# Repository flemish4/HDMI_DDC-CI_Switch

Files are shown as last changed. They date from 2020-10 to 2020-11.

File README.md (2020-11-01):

# HDMI_DDC/CI_KVM

## Introduction

This project aims to replicate the functionality of a KVM switch using the DDC/CI capability built into most monitors. 
This avoids the need for any complex switching of high frequency HDMI/DP signals so is cheap to implement and does not constrain the resolution or frequency of the monitor.
The additional important benefit is that most KVM switches do not handle EDID/hot plug detection correctly. This means that when the switch connects PC2 to the monitor(s), PC1 forgets that the monitors exist, and rearranges all the windows - annoying! This project avoids this problem because the monitors are all directly connected to each PC, so the monitor always provides EDID data and HPD signal.
It also serves as a demonstrator for communicating with monitors over DDC/CI.

## Status

<b>This project is currently dead because if a monitor is set to an input which is not active, most monitors go to sleep. From this sleep state, even when the input is changed using DDC/CI monitors often do not wake up.
I am not sure how monitors detect whether an input is active and if this could be fooled. I suspect it detects some of the high frequency HDMI signals. If these were replicated there wouldn't be much benefit over a normal KVM.
<h3>If anyone has a solution to this problem please get in touch and we can have cheap multi monitor KVMs!</h3>
If your monitors correctly switch away from idle inputs to active inputs, this project may work well.</b>

Normal KVMs should implement a DDC/CI/HPD scheme, where each PC always believes it is connected to its monitors at all times, this project shows that it isn't very difficult. Simply read EDID from the monitor, then repeat this every time the PC asks for the information. If anyone is aware of a dual monitor KVM that handles this correctly please let me know! :)

## Setup

The project was tested on an arduino uno, with vscode and platformio as the ide. The only external components required are: 4 resistors (i2c pullups), 2 resistors (HDMI 5v current limiting - should really be an IC), 5 push buttons and two female HDMI ports with only have 5v, GND, I2CDAT, I2CCLK signals connected. These are connected to a spare input on each monitor (so each monitor requires 3+ inputs).
See end of readme for schematic and diagram.
## Usage - Overview

The project implements 5 buttons, 1 'setup' button and 4 'mode' buttons.
See end of readme for flow diagram.
At idle, the 'mode' buttons can either select a preset mode, or can relate to each monitor and each button will cycle through each input for that monitor. You can switch between these two idle states by pressing the 'setup' button.
To set presets, simply hold setup, then within 1 second press the button you wish to set a preset on, wait 3 seconds. This will set the preset to the current state of the monitors.
There is also a settings menu which can be accessed by pressing 'setup' for 4 seconds.
You can configure :
    default (turn on) idle state (preset selection or input switching)
    default (turn on) monitor state (leave monitors as they are, change them to the inputs selected when the switch turned off, or any of the presets)
    input selection options (0: Automatic detection (order will likely be wrong), 1: Match mode order (likely in order but may miss extras), 2: Match mode order + autodetected (likely in order but may have extras), 3: Automatic detection (ordering will likely be wrong) - test ALL possible values) 
At any time in the menu, press 'setup' to exit the menu.

## Initial Setup and Normal Use

 1. Turn on for the first time with monitors connected and PCs turned on
 2. Press and hold 'setup' for 5 seconds, until the LED flashes in short single beat pulses - this is the settings menu
 3. Press Button 2 (the third mode button, the 4th button if you include the setup button) - this selects input setup
 4. Press Button 0 for automatic input detection - this will take a few seconds to cycle through every input on every monitor
3. Press 'setup' to return to idle
4. Press 'setup' again to switch to input selection state
5. Press Buttons 0 and 1, the monitors should cycle through their inputs
6. Press 'setup' then one of the mode buttons and hold for 5 seconds - this sets the current input configuration as that mode - repeat until all desired modes are set
1. Press 'setup' to enter mode selection state
1. Press any of the set mode buttons - the monitors should switch to that configuration!

## Full settings menu description
Pressing 'setup' at any time will return you to idle, not in settings menu.
Completing any operation in settings menu will return you to Main settings menu.
|Level 0|Level 1|Level 2|Level 3|
|--|--|--|--|
|Main|
||0. Change setup button behaviour||
|||0. Mode select|
||| 1. Input select|
||1. Change turn on behaviour||
|||0. Do not change|
|||1. As turn off state|
|||2. Select mode|
||||0,1,2,3. Respective mode is set|
||2. Configure monitor input switching||
|||0. Automatic detection|
|||1. Extract in order from preset modes|
|||2. Extract from modes then add any extras found during automatic detection|
||3. (Not fully implemented) Change serial debug levels||
|||0. No debug|
|||1. Errors only|
|||2. Warnings and errors|
|||3. All debug|

## Future if sleep issue is overcome
If the sleep problem could be fixed, the next phase was to implement HDMI passthrough. In this case, HDMI signals would be passed through so that no extra input is required. The only additional complexity is a gate between the HDMI input and output on the i2c lines, to enable the HDMI_DDC/CI_KVM to change the input (removing the PC master). This should be relatively simple, if PCs are able to notice this disconnect, it may be possible to hold the i2c clk line low until the input switching is complete, which should make the PC wait.

## References
|Name|Description/use|Link|
|--|--|--|
|DDC/CI VESA specification|Contains semi helpful descriptions of how DDC/CI i2c communication works - actual VCP codes are in appendix|https://milek7.pl/ddcbacklight/ddcci.pdf|
|MCCS (VCP) VESA specification|Contains VCP descriptions, layout of data|https://milek7.pl/ddcbacklight/mccs.pdf|
|ControlMyMonitor|Useful utility for using DDC/CI from windows - used to trigger communication which captured for reference|https://www.nirsoft.net/utils/control_my_monitor.html|
|ddcutil|Similar to ControlMyMonitor but linux only looks well maintained - documentation contains useful snippets|https://www.ddcutil.com/|

## Diagrams

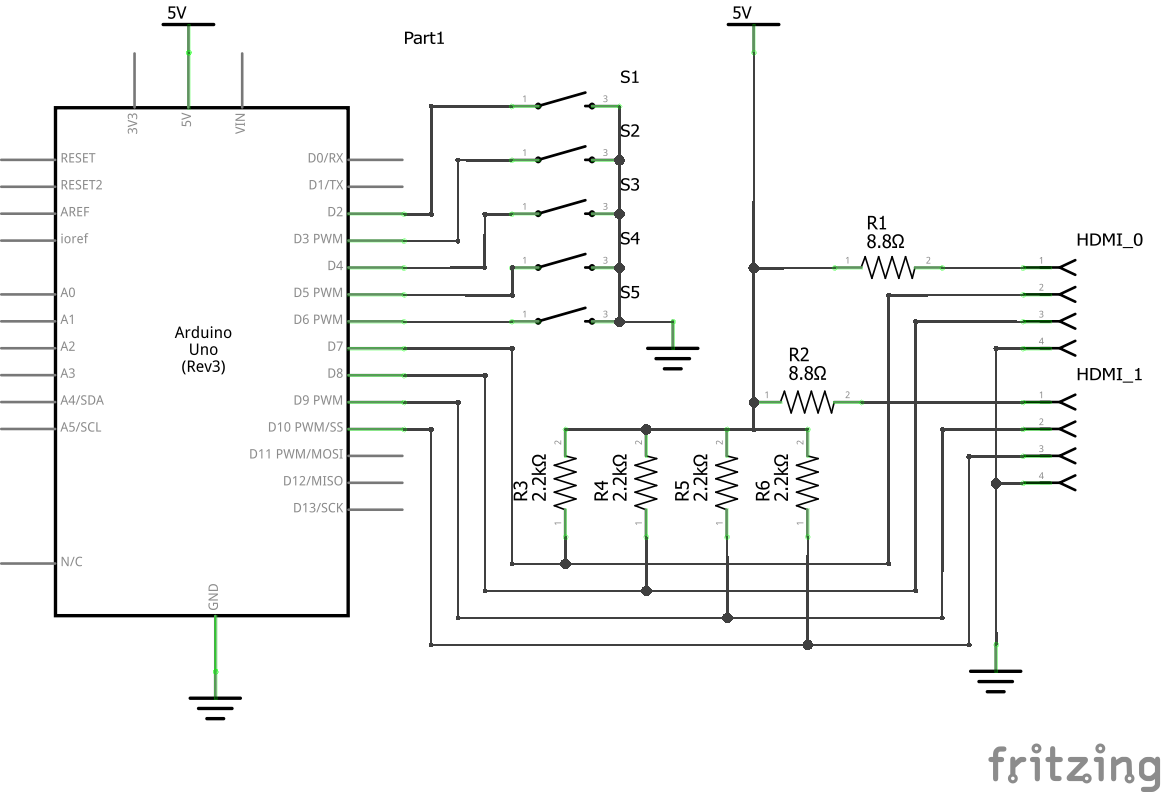
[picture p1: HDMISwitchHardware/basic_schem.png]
Schematic

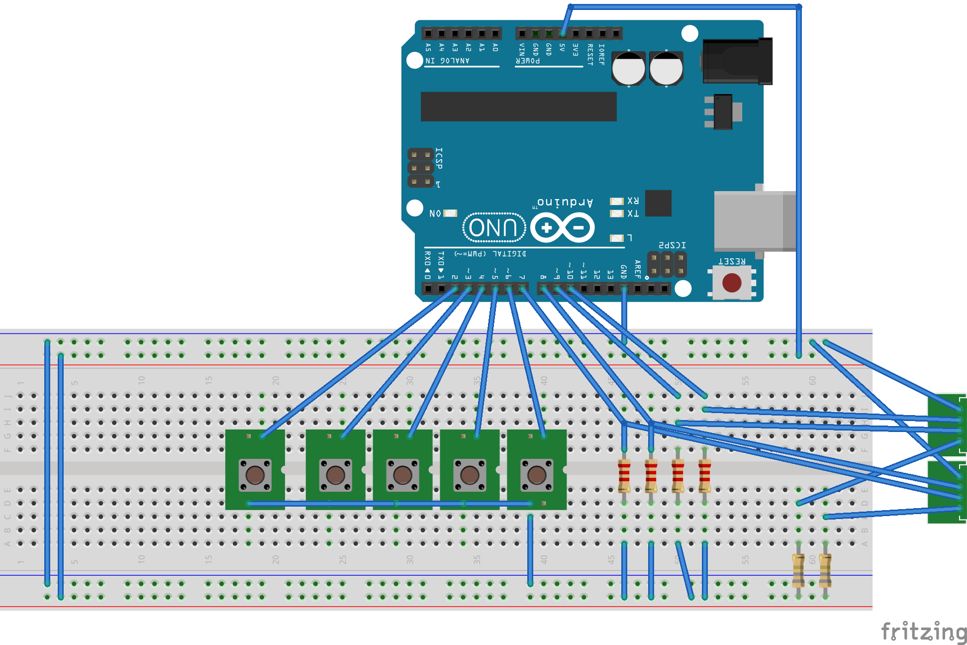
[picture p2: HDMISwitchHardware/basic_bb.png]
Fritzing

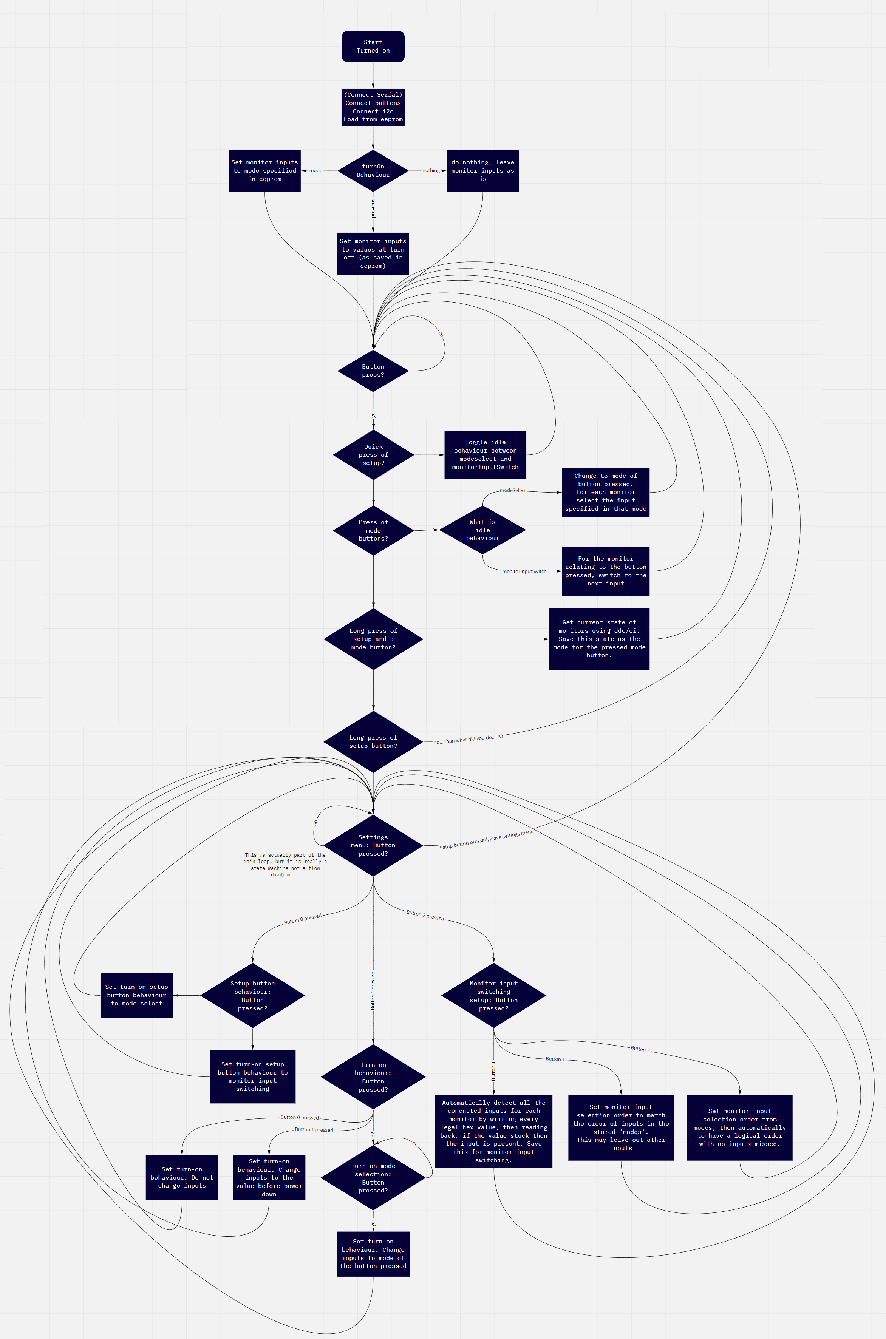
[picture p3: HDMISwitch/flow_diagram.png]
Flow diagram


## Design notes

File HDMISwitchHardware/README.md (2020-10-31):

This folder would contain hardware schematics and board layouts for a full KVM switch based on the ddc/ci solution - including USB switch and hub, and possibly hotkey detection (although this is difficult with usb).

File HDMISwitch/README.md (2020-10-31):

This is the bulk of the repo.
It contains a single source file main.cpp which contains the whole arduino source (great organisation I know).

It also contains copies of the source of 3 libraries which should probably be handled some other way.... :
Bounce2  : switch debouncing       : https://github.com/thomasfredericks/Bounce2
SoftWire : software i2c            : https://github.com/stevemarple/SoftWire
TimerOne : timer interrupt handler : https://github.com/PaulStoffregen/TimerOne

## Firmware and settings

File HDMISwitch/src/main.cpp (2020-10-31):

#include <Arduino.h>
#include <EEPROM.h>
#include <Bounce2.h>
#include <SoftWire.h>
#include "TimerOne.h"
#define ARDBUFFER 16
#include <stdarg.h>

//#include <AsyncDelay.h>

// REVISITS:
// Add optional serial debug function and reporting
// Check all revisits
// eeprom stored values should probably be classes to group the dimensions, address, data, load and store functions.

// Constants
  // Fundamental 
    // i2c/ddc values
      const byte lenMagicNum = 0x80;
      const byte hostSlaveAddr = 0x51;
      const byte edidHeader[8] = {0x00, 0xFF, 0xFF, 0xFF, 0xFF, 0xFF, 0xFF, 0x00};
      const byte maxDdcInputValSpec = 0x12;
      const byte maxDdcInputValMax  = 0xFF;

  // Configurable
    // Design Constraints 
      const int numMonitors = 2;
      const int maxSupportedMonitorInputs = 8;
      const int numModes = 4;

    // Pin Definitions
      const int ledPin = 13;
      const int setupButtonPin = 2;
      const int modeButtonPins[numModes] = {3,4,5,6};
      const int i2cPins[numMonitors][2] = {{7,8},{9,10}};

    // Timing delays
      const int i2cOperationDelay = 250; // ms between operations
      const int i2cReadWriteDelay = 50; // ms between writing and reading from a location
      const int loopDelay = 50; // 20 times per second
      const int settingsMaxCount = 3*(1000/loopDelay);

    // Settings menu
      const int settingsMenu[6][4] = {{1,2,4,5}, // Main - 0: Change setup button behaviour, 1: Change turn on behaviour, 2: Configure monitor input switching, 3: enable or disable serial
                                      {0,0,0,0}, // Setup button behaviour - 0: mode select, 1: input cycling
                                      {0,0,3,2}, // Turn on behaviour - 0: Do not change, 1: As turn off, 2: choose mode on next page
                                      {0,0,0,0}, // Turn on behaviour mode select - 0: turn on to mode 0, 1 turn on to mode 1 etc.
                                      {0,0,0,0}, // Monitor input switching config : 0: Automatic detection (order will likely be wrong), 1: Match mode order (likely in order but may miss extras), 2: Match mode order + autodetected (likely in order but may have extras), 3: Automatic detection (ordering will likely be wrong) - test ALL possible values
                                      {0,0,0,0}  // Enable or disable serial debug levels : 0 : None, 1: Errors, 2: Warnings, 3: Debug
                                    };

    // Logging
      //const char debugLevelStr[4][5] = {"NORM", "ERR ", "WARN", "INFO"};

    // LED flashing patterns
      // 3 states + 2 idleBehaviour + 6 menu pages
      const unsigned long msPerBit  = 4194304/16; // Roughly a second, 16bit resolution during that time
      const int numStates = 4 + 6;
      const unsigned int ledFlashCycles[numStates]= { // REVISIT : For a larger menu this can easily be extended so each sequence takes longer, more resolution.
                                                      0b1111111111111111, // Idle Mode select
                                                      0b1111110011111100, // Idle Input select
                                                      0b1100110011001100, // Waiting for config
                                                      0b1000001000001000, // Config menu 0
                                                      0b1010000001010000, // Config menu 1
                                                      0b1010100000000000, // Config menu 2
                                                      0b1010101000000000, // Config menu 3
                                                      0b1010101010000000, // Config menu 4
                                                      0b1010101010100000  // Config menu 5
      };


    // Eeprom 
      // Size
        const int eepromSize_idleBehaviour = 1;
        const int eepromSize_turnOnBehaviour = 1;
        const int eepromSize_monitorModes = numModes*numMonitors;
        const int eepromSize_currentMonitorMode = numMonitors;
        const int eepromSize_monitorInputs = numMonitors*maxSupportedMonitorInputs;

      // Addresses
        const int eepromAddr_idleBehaviour = 0;
        const int eepromAddr_turnOnBehaviour = eepromAddr_idleBehaviour + eepromSize_idleBehaviour;
        const int eepromAddr_monitorModes = eepromAddr_turnOnBehaviour + eepromSize_turnOnBehaviour;
        const int eepromAddr_currentMonitorMode = eepromAddr_monitorModes + eepromSize_monitorModes;
        const int eepromAddr_monitorInputs = eepromAddr_currentMonitorMode + eepromSize_currentMonitorMode;
        //const int eepromMaxAddr = eepromAddr_monitorInputs + eepromSize_monitorInputs;


// Semi constants - loaded from eeprom
  byte idleBehaviour = 0; // 0 is mode select, 1 is input switching                                               
  byte turnOnBehaviour = 0; // 255 is just leave, 254 is previous state, others are just button saves.            
  byte monitorModes[numModes][numMonitors] = {{0xFF, 0xFF},{0xFF, 0xFF},{0xFF, 0xFF},{0xFF, 0xFF}};               
  byte currentMonitorMode[numMonitors] = {0xFF, 0xFF};                                                            
  byte monitorInputs[numMonitors][maxSupportedMonitorInputs] = {{0xFF, 0xFF, 0xFF, 0xFF, 0xFF, 0xFF, 0xFF, 0xFF}, 
                                                                {0xFF, 0xFF, 0xFF, 0xFF, 0xFF, 0xFF, 0xFF, 0xFF}};

  // Eeprom addresses

// State values
  int  state = 0; // 0 - idle, 1 - checking if settings mode, 2 - settings mode
  bool doneAction = 0;
  int  settingsCounter = 0;
  int  settingsPage  = 0; // 0 is main menu, 1 is setup button behaviour (values 0, 1 as above), 2 is turn on behaviour 
  bool modeSelected = false;
  int  selectedMode = -1;
  int  debugLevel = 3;
  bool ledState = false;
  volatile byte ledCounter = 0;

// Input objects
  // Buttons
    Bounce setupButton = Bounce();
    Bounce * modeButtons = new Bounce[numModes];

  // I2C
    SoftWire *i2cMonitorPorts[numMonitors];
    byte i2cMonitorTxBuffers[numMonitors][32];
    byte i2cMonitorRxBuffers[numMonitors][32];



//// Generic functions START
  // REVISIT : make this work
  //void debugPrint(int level, const char *str, ...)
  //{
  //  //Serial.println("Attempt to use debugPrint");
  //  if (debugLevel<level) return; // Only print messages that are equal to or less than the debug level
  //  //Serial.print(debugLevelStr[level]);
  //  //Serial.print(": ");
  //  char buffer[256];
  //  va_list args;
  //  va_start(args, str);
  //  vsprintf(buffer, str, args);
  //  va_end(args);
  //  //Serial.println(buffer);
  //}

  bool isValueInArray(byte arr[], int len, byte val)
  {
    //debugPrint(3, "isValueInArray val: %X, len: %d, arr: %X", val, len, arr);
    for (int i = 0; i < len; i++) {
        if (arr[i] == val) {
            //debugPrint(3, "isValueInArray Evaluated as true");
            return true;
        }
      }
    //debugPrint(3, "isValueInArray Evaluated as false");
    return false;
  }

  int whereIsValueInArray(byte arr[], int len, byte val)
  {
    //debugPrint(3, "whereIsValueInArray val: %X, len: %d, arr: %X", val, len, arr);
    for (int i = 0; i < len; i++) {
        if (arr[i] == val) {
            //debugPrint(3, "whereIsValueInArray returned: %d", i);
            return i;
        }
      }
    //debugPrint(3, "whereIsValueInArray Evaluated as false");
    return -1;
  }

  bool doArraysMatch(int len, byte a[], const byte b[])
  {
    //debugPrint(3, "doArraysMatch len: %d, a: %X, b: %X", len, a, b);
    for (int i=0; i<len; i++) 
    {
      if (a[i] != b[i])  {
        //debugPrint(3, "doArraysMatch Evaluated as false");
        return false;
      }
    }
    //debugPrint(3, "doArraysMatch Evaluated as true");
    return true;
  }

  void print_byte_array(byte Buffer[], int len)
  {
    for (int i; i<len; i++) 
    {
      //Serial.print("0x");
      //Serial.print(Buffer[i]>>4,  HEX);
      //Serial.print(Buffer[i]&0x0F,HEX);
      //Serial.print(" ");
    }
  }

  int getMaxSetBit(bool arr[], int len) 
  {
    //debugPrint(3, "getMaxSetBit len: %d, arr: %X", len, arr);
    for (int i=0; i<len; i++) {
      if (arr[i]) {
        //debugPrint(3, "getMaxSetBit returned: %d", i);
        return i;
      }
    }
    //debugPrint(3, "getMaxSetBit returned: -1");
    return -1;
  }


  // startAddr is the start of the location in eeprom where the data is stored
  // arr is an N dimensional array
  // len is the total length of the array so multiplication of each dimension
  // - we ignore the actual shape of the array - so long as it is consistently written and read it shouldn't matter
  // isRead indicates that the access is to be a read, otherwise writes.
  void eepromAccessor(int startAddr, byte arr[], int len, bool isRead)
  {
    for (int i=0; i<len; i++) {
      int addr = startAddr + i;
      if (isRead) {
        arr[i] = EEPROM.read(addr);
      } else { // is write 
        EEPROM.write(addr, arr[i]);
      }
    } 
  }
//// Generic functions END


//// Arduino Debug START

// REVISIT : the state system should be cleaned up somewhat to remove the need for the special ledStateNumber operation.
void flashLED() {
  int ledStateNumber = state == 0 ? idleBehaviour : 1 + state + settingsPage;
  digitalWrite(ledPin, bitRead(ledFlashCycles[ledStateNumber], ledCounter));
  ledCounter = ledCounter >= 15 ? 0 : ledCounter + 1;
}


//// Arduino Debug END


//// I2C Functions START

  bool i2cWrite(int monitor, byte addr, int numBytes, byte Buffer[])
  {
    //debugPrint(3, "i2cWrite numBytes: %d, monitor: %d, addr: %X, buffer: %X", numBytes, monitor, addr, Buffer);
    int result;
    i2cMonitorPorts[monitor]->beginTransmission(addr); 
    for (int i=0; i<numBytes; i++) {
      i2cMonitorPorts[monitor]->write(Buffer[i]);
    }
    result = i2cMonitorPorts[monitor]->endTransmission();
    //debugPrint(3, "i2cWrite result: %d", result);
    return result == 0;
  }

  bool i2cRead(int monitor, byte addr, byte Buffer[], int startIdx, int numBytes)
  {
    //debugPrint(3, "i2cRead startIdx: %d, numBytes: %d, monitor: %d, addr: %X", startIdx, numBytes, monitor, addr);
    int i = startIdx;
    i2cMonitorPorts[monitor]->requestFrom((uint8_t)addr, (uint8_t)numBytes, (uint8_t)true);
    while (i2cMonitorPorts[monitor]->available()){
      Buffer[i] = i2cMonitorPorts[monitor]->read();
      i+=1;
    }
    //debugPrint(3, "i2cRead read num: %d, out of: %d", i-startIdx, numBytes);
    //Serial.print("numBytesRead = ");
    //Serial.println(i-startIdx);
    if (i-startIdx != numBytes) {
      return false;
    }
    return true;
  }
//// I2C Functions END


//// DDC Functons

  bool isChecksumValid(byte Buffer[], int len) {
    byte calcChecksum = 0;
    for (int i=0; i<len-1; i+=1) {
      calcChecksum ^= Buffer[i];
    }
    //debugPrint(3, "isChecksumValid checksum: %X, from: %X", calcChecksum, Buffer);
    return calcChecksum == Buffer[len-1];
  }

  bool ddcWrite(int monitor, byte addr, int numBytes, byte Buffer[])
  {
    //debugPrint(3, "ddcWrite monitor: %d, numBytes: %d, addr: %X, Buffer: %X", monitor, numBytes, addr, Buffer);
    byte trueAddr = addr << 1 | 0;
    byte trueLen = numBytes | lenMagicNum;
    byte checkSum = trueAddr ^ hostSlaveAddr ^ trueLen;

    //Serial.print("trueAddr: ");
    //Serial.print(trueAddr, HEX);
    //Serial.print(", ");
    //Serial.print("trueLen: ");
    //Serial.print(trueLen, HEX);
    //Serial.print(", ");
    //Serial.print("checkSum: ");
    //Serial.print(checkSum, HEX);
    //Serial.print(", ");

    i2cMonitorPorts[monitor]->beginTransmission(addr);
    i2cMonitorPorts[monitor]->write(hostSlaveAddr);
    i2cMonitorPorts[monitor]->write(trueLen);
    for (int i=0; i<numBytes; i++) {
      i2cMonitorPorts[monitor]->write(Buffer[i]);
      checkSum ^= Buffer[i];
      //Serial.print("Buffer[i]: ");
      //Serial.print(Buffer[i], HEX);
      //Serial.print(", ");
      //Serial.print("checkSum: ");
      //Serial.print(checkSum, HEX);
      //Serial.print(", ");
    }
      i2cMonitorPorts[monitor]->write(checkSum);
    
      //Serial.println("end");
    return i2cMonitorPorts[monitor]->endTransmission() == 0;
  }

//ddcRead(monitor, 0x37, 0x60, bufferInt, 11, 32);
  bool ddcRead(int monitor, byte addr, byte offset, byte Buffer[], int numBytes, bool isDdcWrite = true, int incr = 32) 
  {
    //Serial.print("ddcRead: ");
    //Serial.print("monitor: ");
    //Serial.print(monitor);
    //Serial.print(", addr: ");
    //Serial.print(addr, HEX);
    //Serial.print(", offset: ");
    //Serial.print(offset, HEX);
    //Serial.print(", numBytes: ");
    //Serial.print(numBytes);
    //Serial.print(", incr: ");
    //Serial.println(incr);
    //debugPrint(3, "ddcRead monitor: %d, numBytes: %d, addr: %X, offset: %X", monitor, numBytes, addr, offset);
    byte wrData[2] = {};
    bool result = true;
    int thisNumBytes;

    for (int i=0; i<numBytes; i+=incr) {
      if (i>0) {
        delay(i2cOperationDelay);
      }
      thisNumBytes = min(numBytes-i, 32);
      wrData[1] = i+offset;

      if (isDdcWrite) {
        wrData[0] = 0x01;
        result = result & ddcWrite(monitor, addr, 2, wrData);
      } else {
        result = result & i2cWrite(monitor, addr, 1, &wrData[1]);
      }
      delay(i2cReadWriteDelay);
      //result = result & i2cWrite(monitor, addr, 1, wrData);
      result = result & i2cRead(monitor, addr, Buffer, i, thisNumBytes);

    }

    // Check checksum 
    //Serial.print(", result: ");
    //Serial.println(result);
    result = result ; //& isChecksumValid(Buffer, numBytes); REVISIT : Checksum not working correctly
    //Serial.print(", result: ");
    //Serial.println(result);

    return result;
  }

  bool edid_read(int monitor, int len)
  {
    byte Buffer[len];
    bool match;
    ddcRead(monitor, 0x50, 0x00, Buffer, len, false, 32);
    match = doArraysMatch(8, Buffer, edidHeader);
    ////Serial.print("EDID data: ");
    //print_byte_array(Buffer, 256);
    ////Serial.println("");
    //debugPrint(3, "edid_read monitor: %d, len: %d, match: %X", monitor, len, match);
    return match;
  }
//// DDC Functons END


//// Monitor Control Functions START
  bool is_monitor_connected(int monitor) {
    bool result = edid_read(monitor, 8);
    //debugPrint(3, "is_monitor_connected monitor: %d, connected?: %X", monitor, result);
    return result;
  }

  bool readMonitorInput(int monitor, byte *inputVal) 
  {
    byte bufferInt[11] = {};
    bool result = ddcRead(monitor, 0x37, 0x60, bufferInt, 11, true, 32);
    //Serial.print("readMonitorInput bufferInt = ");
    print_byte_array(bufferInt, 11);
    //Serial.println("");
    //Serial.println(bufferInt[9]);
    *inputVal = bufferInt[9];
    //debugPrint(3, "readMonitorInput monitor: %d, inputVal: %X, success?: %X", monitor, *inputVal, result);
    return result;
  }

  bool writeMonitorInput(int monitor, byte inputVal) 
  {
    if (inputVal == (byte)0xFF) return false;
    byte bufferInt[4] = {0x03, 0x60, 0x00, inputVal};
    bool result = ddcWrite(monitor, 0x37, 4, bufferInt);
    //debugPrint(3, "writeMonitorInput monitor: %d, inputVal: %X, success?: %X", monitor, inputVal, result);
    return result;
  }


  bool selectMonitorInput(int monitor, byte inputVal) 
  {
    byte inputValRead = 0xFF;
    //Serial.println("selectMonitorInput pre ");
    //Serial.println(monitor);
    //Serial.println(inputVal);

    // write to monitor to select input
    writeMonitorInput(monitor, inputVal);

    delay(i2cOperationDelay); 

    // read back from monitor, if the value has stuck then the input is present
    readMonitorInput(monitor, &inputValRead);

    //Serial.print("selectMonitorInput post ");
    bool result = inputVal == inputValRead;
    //debugPrint(3, "selectMonitorInput monitor: %d, inputVal: %X, success?: %X", monitor, inputVal, result);
    //Serial.print(inputVal);
    //Serial.print(" ");
    //Serial.print(inputValRead);
    //Serial.print(" ");
    //Serial.println(result);
    return result;
  }
//// Monitor Control Functions END


//// Settings Helper Functions START
  byte getMonitorInputsMaxValidIdx(int monitor) {
    for (int i=0; i<maxSupportedMonitorInputs; i++) {
      if (monitorInputs[monitor][i] == (byte)0xFF) {
        //debugPrint(3, "getMonitorInputsMaxValidIdx monitor: %d, return: %d, success?: %X", monitor, i-1);
        return i-1;
      }
    }
    //debugPrint(1, "getMonitorInputsMaxValidIdx This is very odd");
    return 255;
  }

  void getMonitorStates(byte monitorStates[]) 
  {
    byte result;
    byte inputVal;
    // For each monitor
    for (int i=0; i<numMonitors; i++) {
      //Serial.print("GetMonitorStates: ");
      //Serial.println(i);
      result = 0xFF; // Default value -- invalid
      // Check if active
      if (is_monitor_connected(i)) { // Check if monitor is on -- maybe unnecessary
        //Serial.println("is connected");
        if (readMonitorInput(i, &inputVal)) // Read from ddc reg 60 (input) - only update result if it was successful
        {
          //Serial.println("Got monitor input read successfully");
          //Serial.println(inputVal);
          result = inputVal; // update result - monitor input value
        }
      }
      monitorStates[i] = result; // Populate array
      //debugPrint(3, "getMonitorStates monitorStates[%d]: %X", i, result);
    }
  }

  int getPossibleInputs(int monitor, int maxValue, byte possibleInputs[]) {
    int inputCount = 0;
    bool inputPresent;
    for (int i=0; i<=maxValue; i++) {
      inputPresent = selectMonitorInput(monitor, i);
      if (inputPresent) {
        possibleInputs[inputCount] = i;
        inputCount += 1;
      }
      delay(i2cOperationDelay);
    }
    //debugPrint(3, "getPossibleInputs inputCount: %d, possibleInputs: %X", inputCount, possibleInputs);
    return inputCount;
  }
//// Settings Helper Functions END
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
void loop()
{
  delay(loopDelay); // Sample inputs 20 times per second... Maybe sleep and wakeup on interrupt
  //debugPrint(3, "Top of loop");
  ////Serial.println("Top of loop");

  // Temporary values
  bool setupButtonStatus = false;
  bool modeButtonStatus[numModes] = {false,false,false,false};

  // Temporarily, just sample here
  setupButton.update();
  setupButtonStatus = !setupButton.read();
  for (int i=0;i<numModes;i++)
  {
    modeButtons[i].update();
    modeButtonStatus[i] = !modeButtons[i].read();
  }
  // end sample

  // Which mode button is pressed?
  selectedMode = getMaxSetBit(modeButtonStatus, numModes) ;
  modeSelected = selectedMode > -1 ;

  //debugPrint(3, "loop done reads");
  ////Serial.println("Done reads");

  // REVISIT : sometimes this gets split across 2-3 lines... But inconsistently 
  //Serial.print  ("\tstate          : ");
  //Serial.print  (state          );
  //Serial.print  ("\tidleBehaviour   : ");
  //Serial.print  (idleBehaviour  );
  //Serial.print  ("\tturnOnBehaviour : ");
  //Serial.print  (turnOnBehaviour);
  //Serial.print  ("\tdoneAction     : ");
  //Serial.print  (doneAction     );
  //Serial.print  ("\tsettingsCounter: ");
  //Serial.print  (settingsCounter);
  //Serial.print  ("\tsettingsPage   : ");
  //Serial.print  (settingsPage   );
  ////Serial.print  ("\tmodeSelected   : ");
  ////Serial.print  (modeSelected   );
  ////Serial.print  ("\tselectedMode   : ");
  ////Serial.print  (selectedMode   );
  ////Serial.print  ("\tdebugLevel     : ");
  ////Serial.print  (debugLevel     );
  //Serial.print  ("\tledState       : ");
  //Serial.println(ledState       );

  // Main state machine
  if (!doneAction) {
    if (state == 0) { // idle
        
      if (setupButtonStatus) {
        state = 1; // Check for update settings mode
      } else if (modeSelected) {
        if (idleBehaviour == 0) {
          setMode(selectedMode);
        } else if (idleBehaviour == 1) {
          incrementInput(selectedMode);
        }
        doneAction = true;
      }
    } else if (state == 1) { // Checking if going into settings
      settingsCounter += 1;
      if (!setupButtonStatus) {
        settingsCounter = 0;
        state = 0;
        idleBehaviour = !idleBehaviour;
        doneAction = true;
      } else {
        if (settingsCounter >= settingsMaxCount) {
          doneAction = true;
          settingsCounter = 0;
          if (modeSelected) {
            saveMode(selectedMode);
            state = 0; // go back to idle
          } else {
            state = 2; // go into settings mode
          }
        }
      }
    } else if (state == 2) { // Settings mode
      if (setupButtonStatus) {
        // Exit settings mode
        state = 0;
        settingsPage = 0;
        doneAction = true;
      } else if (modeSelected) {

        // Check menu state for action to perform
        switch (settingsPage) {
          case 1:
            setSetupMode(selectedMode);
            break;
          case 2:
            setDefaultMode(0, selectedMode);
            break;
          case 3:
            setDefaultMode(1, selectedMode);
            break;
          case 4:
            setMonitorInputs(selectedMode);
            break;
          case 5:
            setDebugLevel(selectedMode);
            break;
        }

        // Navigate menu
        ////Serial.println(settingsMenu[settingsPage]);
        //Serial.println(modeSelected);
        //Serial.println(settingsMenu[settingsPage][selectedMode]);
        settingsPage = settingsMenu[settingsPage][selectedMode];
        doneAction = true;
      } // If no button pressed, do nothing

    } else {
      // If in unknown state, go back to idle
      state = 0;
    }
  } else {
    if (!setupButtonStatus && !modeSelected) {
      doneAction = false;
    }
  }
  ////Serial.println("End of loop");


}

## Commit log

2020-10-28 Structure complete, filling in low level functions
    [HDMISwitchHardware.kicad_pcb, HDMISwitchHardware.sch]
2020-10-28 Implemented software i2c. Started populating low level functions
2020-10-29 First pass complete. Need to add eeprom functionality, error handling, debug serial, test....
    [main.cpp]
2020-10-30 Started debug, menu working. Not reading back correctly
    [main.cpp]
2020-10-31 Eeprom working. LED status working. Added readme with bad news.
2020-10-31 Created readme for i2cSniff folder
2020-10-31 Added frizing schematics
    [basic.fzz]
2020-11-01 added flow diagram
